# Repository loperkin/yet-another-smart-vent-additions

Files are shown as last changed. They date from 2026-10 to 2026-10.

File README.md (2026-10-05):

# Yet Another Smart Vent — Additions

Modernized **ESPHome configuration, Home Assistant control examples, and additional 3D-printable frame designs** for the excellent **Yet Another Smart Vent** project created by BrobstonCreations.

> **Important:** I did not create the original Yet Another Smart Vent hardware or mechanical vent design. This repository is a companion to that project and contains my own additions along with an updated ESPHome configuration for current versions of ESPHome.

## Original Project

The smart vent hardware and original design were created by **BrobstonCreations**:

https://github.com/BrobstonCreations/yet-another-smart-vent

If you're building one of these vents from scratch, **start there**.

Their repository contains the original:

- Mechanical vent design
- Louvers and vent mechanism
- Electronics and component information
- Assembly instructions
- ESPHome implementation
- 3D-printable parts and original frame sizes

A huge thank you to **BrobstonCreations** and the contributors to that project for designing it and making it available to the community.

This repository exists because I built their project, started using it around my house, and eventually needed some things that weren't available in the original version.

---

# What This Repository Adds

After building the original Yet Another Smart Vent, I ran into two things I wanted to change.

First, the original ESPHome configuration was written for a much older version of ESPHome. ESPHome has changed considerably since then, so getting the vents running on a current installation required a number of updates.

Second, I needed vent frame sizes and configurations that weren't included with the original project.

Rather than changing or replacing the upstream project, I'm keeping those additions here.

This repository contains:

- Updated YAML for current ESPHome versions
- Updated servo configuration and behavior
- Home Assistant focused controls
- Example room-level HVAC automation logic
- Sensor failure fail-safe behavior
- Additional 3D-printable vent frames
- Notes and improvements from using the vents in a real Home Assistant installation

Think of this as a **modern companion to the original project**, not a replacement for it.

---

# Updated ESPHome Configuration

The original Yet Another Smart Vent includes an ESPHome configuration for controlling the vent.

Since that configuration was created, ESPHome has gone through a number of changes. When I built my vents, portions of the original configuration needed to be updated before they would work properly with a current ESPHome installation.

The YAML in this repository is my updated version for the vents I'm currently running.

Changes include updates to:

- Current ESPHome syntax and components
- Servo configuration
- Vent position control
- Movement behavior
- Servo detachment after movement
- Home Assistant integration
- Additional controls used by my HVAC automations

The goal isn't to redesign the original vent controller. It's to keep the same basic hardware concept working cleanly with a modern ESPHome and Home Assistant installation.

My current configuration uses:

- **ESP8266 D1 Mini**
- Servo on **D3**   I use the DFRobot DMS-MG90-A
- **50 Hz** servo frequency
- Approximately **7 second** movement transition
- Automatic servo detachment after movement

My vent calibration currently uses approximately:

- **Open:** 0%
- **Closed:** -80%

Servo limits can vary between builds, so **calibrate your own vent before using these values**.

---

# My 3D Printable Frames

The problem: ventproblem
Original covers did not cover all the wall damage from old vents. 

The frame files contained in this repository are **my own designs**.  Frameimage

They are not modified copies of the original project's frame STL files.

I designed these additional frames to interface with the mechanical vent assembly from Yet Another Smart Vent because I needed sizes or configurations that weren't available for some of the registers in my house.

The relationship is essentially:

**BrobstonCreations vent mechanism + my frame = additional vent size**

The frames still depend on the original project's mechanical components, so you'll need the original vent parts to use them.

For the louvers, gears, servo mechanism, electronics mounting, assembly instructions, and other original components, visit:

https://github.com/BrobstonCreations/yet-another-smart-vent

## Available Frame Sizes see 3d Print folder for STL files. 

<!-- Add your actual frame sizes here -->

- 4X10
- 6x12
- TBD

Additional sizes may be added as I install more vents.

---

# Licensing & Attribution

The original **Yet Another Smart Vent** project is the work of BrobstonCreations and is distributed under its own license.

Original project:

https://github.com/BrobstonCreations/yet-another-smart-vent

This repository does not claim ownership of the original vent mechanism, hardware design, documentation, or other upstream work.

The additional 3D-printable frames included here are my own original designs created to interface with that system.

The updated ESPHome configuration is provided to help users run this hardware with current versions of ESPHome and Home Assistant.

Please refer to the original repository for its licensing terms and attribution requirements when using or modifying material originating from that project.

And if this repository helps you build one, please give the **original Yet Another Smart Vent project a star as well**. They did the hard part that made these additions possible.

---
## 🙌 Original Project & Attribution

This repository is a companion to the excellent [Yet Another Smart Vent](https://github.com/BrobstonCreations/yet-another-smart-vent) project by BrobstonCreations.

The original project provides the core smart vent design and mechanism. I did not create the original vent mechanism.

This repository contains additions I developed while building and using the project, including:

- Updated configuration for modern ESPHome
- Home Assistant HVAC automation examples
- Additional control and fail-safe logic
- Independently designed 3D-printable vent frames for additional vent sizes
- Notes and improvements from real-world use

If you're building the vent itself, **start with the original project**. This repository is intended to supplement it, not replace it.

## 📜 License

This repository contains work covered by multiple licenses because it includes both derivatives of the original project and independently created additions.

- **Software derived from the original Yet Another Smart Vent project:** AGPL-3.0
- **Original 3D-printable frame designs by Lee Perkins:** CERN-OHL-W-2.0
- **Independently written Home Assistant automations:** MIT
- **Original documentation and media:** Copyright © 2026 Lee Perkins unless otherwise noted
- **Purpose in Practice branding:** All rights reserved

Copyright and licensing for material originating from BrobstonCreations remain with the original project and its contributors.

See [LICENSE.md](LICENSE.md) for complete licensing and attribution information.

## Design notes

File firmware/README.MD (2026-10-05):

# Common Smart Vent Configuration

The Common directory contains the shared ESPHome configuration used by the smart vent devices.

## `yet-another-smart-vent-base.yaml`

This file contains the common configuration for the smart vent, including:

- Servo configuration
- Servo movement range
- Vent open and close scripts
- 25%, 50%, and 75% vent positions
- Home Assistant cover entity
- Position control
- Command lockout
- Servo auto-detach
- Startup behavior

Instead of duplicating this configuration in every vent's ESPHome YAML file, each vent can include this common configuration as a package.

## Installation

Place:

`yet-another-smart-vent-base.yaml`

in your ESPHome configuration directory at:

`esphome/common/`

Your ESPHome directory should look similar to:

```text
esphome/
├── common/
│   └── yet-another-smart-vent-base.yaml
│
├── dining-vent.yaml
├── kitchen-vent.yaml
└── bedroom-vent.yaml
```

> **Important:** The file must be located in the `esphome/common/` directory if you use the package path shown in the examples in this repository.

## Using the Common Configuration

Your individual vent configuration can include the shared configuration using ESPHome packages.

Example:

```yaml
packages:
  vent_base: !include
    file: common/yet-another-smart-vent-base.yaml
    vars:
      servo_transition_length: 7s
      command_lockout: 5s
```

The individual vent YAML can then contain the device-specific configuration such as:

- Device name
- Friendly name
- Wi-Fi configuration
- API configuration
- OTA configuration
- Substitutions or package variables

while the common file handles the actual vent behavior.

## Servo Positions

The current configuration uses the following servo positions:

| Vent Position | Servo Level |
|---|---:|
| 100% Open | 0% |
| 75% Open | -20% |
| 50% Open | -40% |
| 25% Open | -60% |
| Closed | -80% |

Home Assistant still sees the vent as a normal **0–100% damper**. The common configuration translates that requested position into the appropriate servo position.

## Servo Calibration

Servo and vent geometry can vary slightly between builds.

Before final assembly, use the servo-centering utility included with this project to position the servo correctly and verify the mechanical range of the vent.

Do not force the servo beyond the physical limits of the vent mechanism.

---

**Learn it. Build it. Put it into practice.**

*Purpose in Practice*

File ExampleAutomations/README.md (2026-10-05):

### Setup

Before using this automation, replace the example entities with your own:

- `climate.thermostat` — your central HVAC thermostat
- `sensor.room_multi_sensor_temperature` — the temperature sensor for the room
- `cover.room_hvac_vent` — the smart vent for the room

The vent positions can also be adjusted for your installation.

| HVAC State | Room Condition | Vent Position |
| --- | --- | ---: |
| Cooling | Room above target | 100% |
| Cooling | Room at or below target | 0% |
| Heating | Room below target | 50% |
| Heating | Room at or above target | 0% |
| Idle | Any | 100% |
| Sensor unavailable | 3+ minutes | 100% |

### Why the Fail-Safe?

The automation intentionally defaults to an **open vent** when valid room-temperature data isn't available.

A disconnected, failed, or unavailable temperature sensor should not cause a smart vent to remain closed indefinitely.

This example is intended as a starting point. Adjust the temperature logic and vent positions to match your HVAC system, room layout, and airflow requirements.

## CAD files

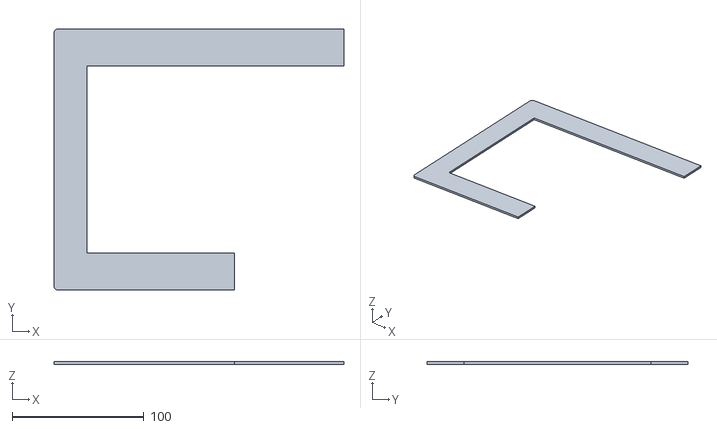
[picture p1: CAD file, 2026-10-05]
3dprintFrames/Frame 6x12 vent Left.stl
220.0 x 198.0 x 2.00

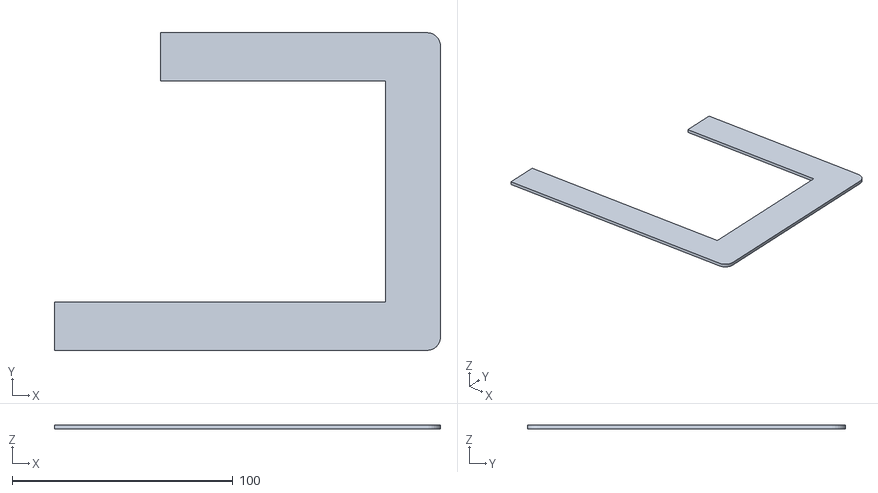
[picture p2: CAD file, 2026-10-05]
3dprintFrames/Frame 4x10 vent Right.stl
175.0 x 144.0 x 2.00

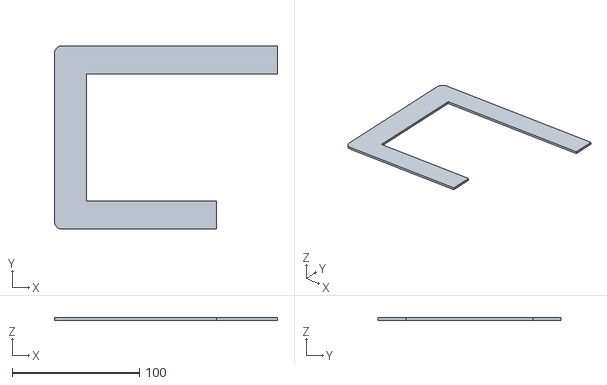
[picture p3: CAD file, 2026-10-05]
3dprintFrames/Frame 4x10 vent - Left.stl
175.0 x 144.0 x 2.00

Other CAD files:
3dprintFrames/Frame 6x12 vent Right.stl
